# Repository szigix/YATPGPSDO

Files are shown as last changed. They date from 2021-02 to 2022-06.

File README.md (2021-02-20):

# YATPGPSDO
## Yet Another TruePosition GPSDO

This is a hardware and the corresponding firmware implemented on an STM32 BluePill board that drives a TruePosition 
GPS Disciplined Oscillator board to provide frequency reference.

For details see [my blog](https://diysquared.blogspot.com/2021/02/yatg-yet-another-trueposition-gpsdo.html).

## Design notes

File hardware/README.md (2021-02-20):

# YATPGPSDO hardware
Hardware design files for Yet Another TruePosition GPSDO
EDA software: [KiCAD](https://kicad.org/)

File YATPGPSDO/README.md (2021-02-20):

# Source for YATPGPSDO
## Yet Another TruePosition GPSDO
Arduino ide source code
Compile with 'Genetric STM32F103C Series' device under Arduino.

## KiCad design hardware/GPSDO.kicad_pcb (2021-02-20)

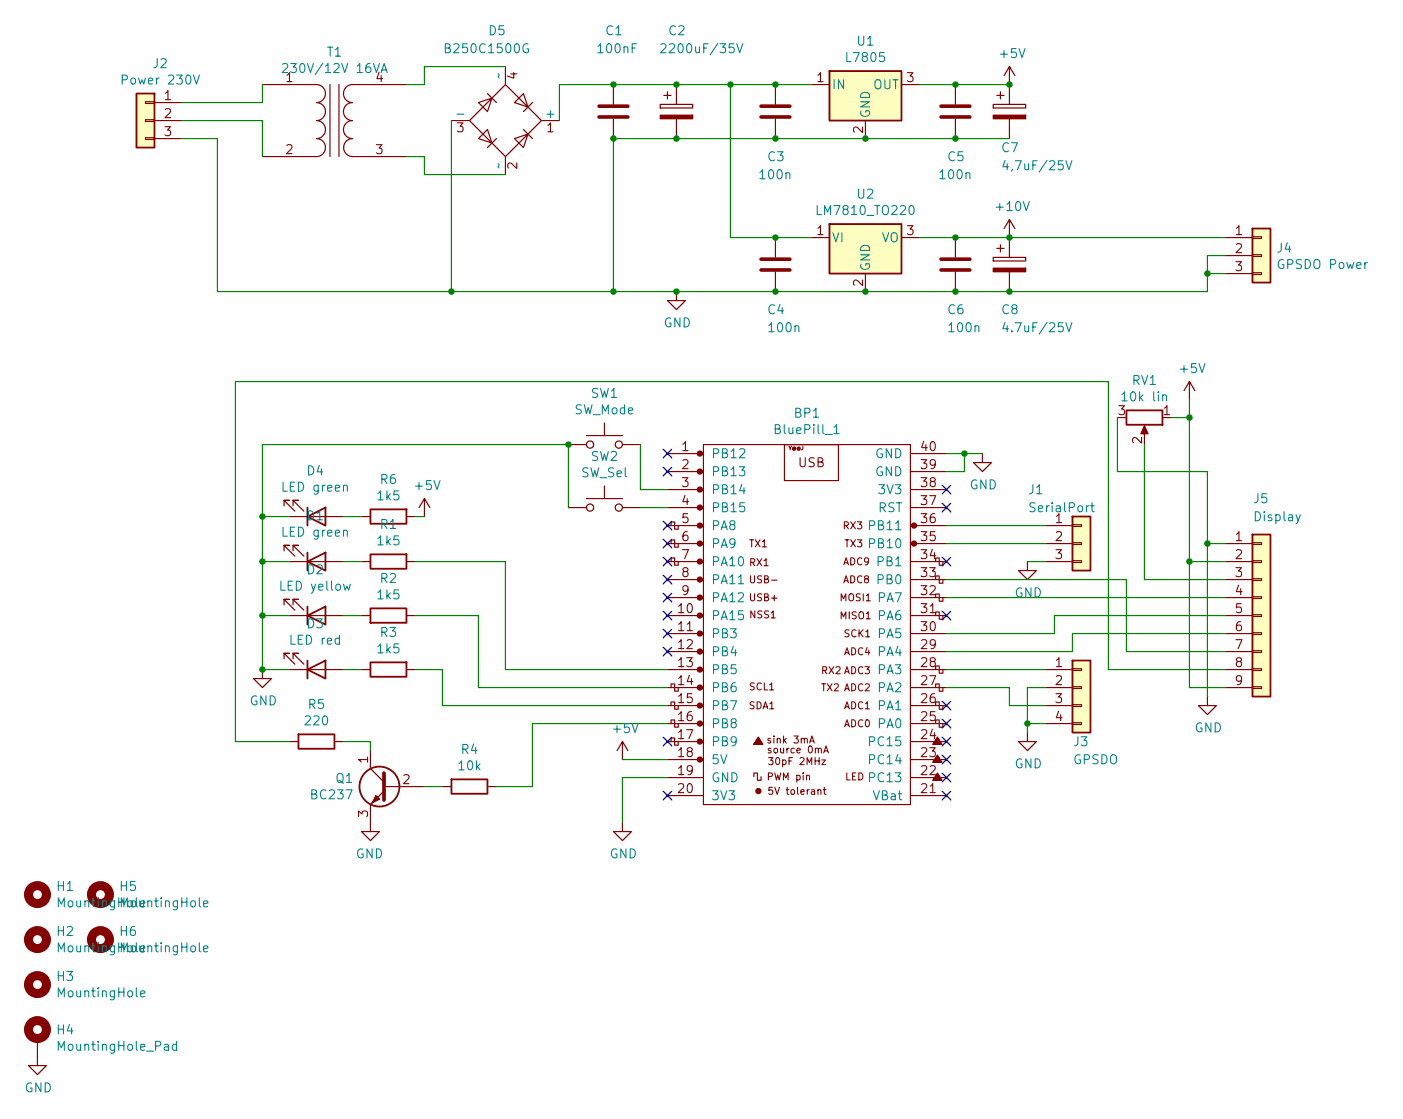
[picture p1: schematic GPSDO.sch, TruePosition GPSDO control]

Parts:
BP1: BluePill_1; STM32-BluePill
C1: 100nF; C_Disc_D5.0mm_W2.5mm_P2.50mm
C2: 2200uF/35V; CP_Radial_D16.0mm_P7.50mm
C3, C4, C5, C6: 100n; C_Disc_D5.0mm_W2.5mm_P2.50mm
C7: 4,7uF/25V; CP_Radial_D5.0mm_P2.00mm
C8: 4.7uF/25V; CP_Radial_D5.0mm_P2.00mm
D1, D4: LED green; PinHeader_1x02_P2.54mm_Vertical
D2: LED yellow; PinHeader_1x02_P2.54mm_Vertical
D3: LED red; PinHeader_1x02_P2.54mm_Vertical
D5: B250C1500G; Diode_Bridge_Round_D9.8mm
H1, H2, H3, H5, H6: MountingHole; MountingHole_3.2mm_M3_Pad
H4: MountingHole_Pad; MountingHole_3.2mm_M3_Pad_Via
J1: SerialPort; PinHeader_1x03_P2.54mm_Vertical
J2: Power 230V; SolderWire-1.5sqmm_1x03_P6mm_D1.7mm_OD3mm
J3: GPSDO; PinHeader_1x04_P2.54mm_Vertical
J4: GPSDO Power; PinHeader_1x03_P2.54mm_Vertical
J5: Display; PinHeader_1x09_P2.54mm_Vertical
Q1: BC237; TO-92_Inline
R1, R2, R3, R6: 1k5; R_Axial_DIN0207_L6.3mm_D2.5mm_P10.16mm_Horizontal
R4: 10k; R_Axial_DIN0207_L6.3mm_D2.5mm_P10.16mm_Horizontal
R5: 220; R_Axial_DIN0207_L6.3mm_D2.5mm_P10.16mm_Horizontal
RV1: 10k lin; Potentiometer_ACP_CA9-H2,5_Horizontal
SW1: SW_Mode; PinHeader_1x02_P2.54mm_Vertical
SW2: SW_Sel; PinHeader_1x02_P2.54mm_Vertical
T1: 230V/12V 16VA; Transforme_Gerth_Bv_54112
U1: L7805; TO-220-3_Vertical
U2: LM7810_TO220; TO-220-3_Vertical

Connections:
+5V: BP1.18 (5V), C5.1, C7.1, J5.2, J5.9, R6.2, RV1.1, U1.3 (OUT)
+10V: C6.1, C8.1, J4.1, U2.3 (VO)
GND: BP1.19 (GND), BP1.39 (GND), BP1.40 (GND), C1.2, C2.2, C3.2, C4.2, C5.2, C6.2, C7.2, C8.2, D1.1 (K), D2.1 (K), D3.1 (K), D4.1 (K), D5.3 (-), H4.1, J1.3, J2.3, J3.2, J3.4, J4.2, J4.3, J5.1, Q1.3 (E), RV1.3, SW1.2, SW2.2, U1.2 (GND), U2.2 (GND)
unnamed: BP1.3 (PB14), SW1.1
unnamed: BP1.4 (PB15), SW2.1
unnamed: BP1.13 (PB5), R1.2
unnamed: BP1.14 (PB6), R2.1
unnamed: BP1.15 (PB7), R3.2
unnamed: BP1.16 (PB8), R4.1
unnamed: BP1.27 (PA2), J3.3
unnamed: BP1.28 (PA3), J3.1
unnamed: BP1.29 (PA4), J5.6
unnamed: BP1.30 (PA5), J5.5
unnamed: BP1.32 (PA7), J5.4
unnamed: BP1.33 (PB0), J5.7
unnamed: BP1.35 (PB10), J1.2
unnamed: BP1.36 (PB11), J1.1
unnamed: C1.1, C2.1, C3.1, C4.1, D5.1 (+), U1.1 (IN), U2.1 (VI)
unnamed: D1.2 (A), R1.1
unnamed: D2.2 (A), R2.2
unnamed: D3.2 (A), R3.1
unnamed: D4.2 (A), R6.1
unnamed: D5.2 (~~), T1.3 (SA)
unnamed: D5.4 (~~), T1.4 (SB)
unnamed: J2.1, T1.1 (AA)
unnamed: J2.2, T1.2 (AB)
unnamed: J5.3, RV1.2
unnamed: J5.8, R5.2
unnamed: Q1.1 (C), R5.1
unnamed: Q1.2 (B), R4.2

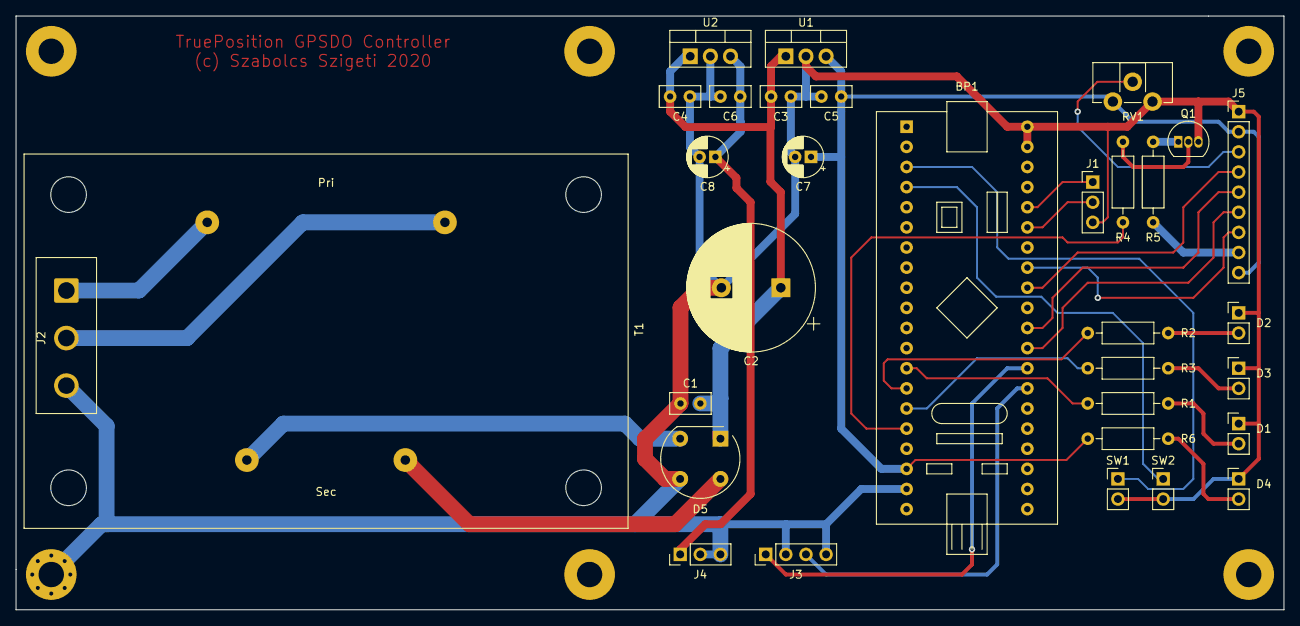
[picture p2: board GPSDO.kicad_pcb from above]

Board: 2 copper layers, 160.0 x 74.9 mm, 38 parts (0 on the bottom side), 30 nets.

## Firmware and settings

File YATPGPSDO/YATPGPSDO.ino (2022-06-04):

/*
   (c) Copyright Szabolcs Szigeti 2020-2021

   Redistribution under GPL V3. See the LICENSE file for details.


  Board: Generic STM32F103C series
  Display: 128x64 ST7920 based bitmap display in serial mode, connected to hw spi

  Additional libraries: Time and U8G2

*/
/*
   Main program for the TruePosition GPSDO
*/
#include <Time.h>
#include <TimeLib.h>
#include <EEPROM.h>
#include <U8g2lib.h>
#include <SPI.h>
#include <Wire.h>

#include "TP_GPSDO.h"

struct CLOCK gpsdoClock;        // Clock related data
struct STATUS gpsdoStatus;      // Everything about the status of the GPSDO
struct SATS gpsdoSats[NUMSAT];  // Data on the tracked satellites
struct ALERTS gpsdoAlerts;      // Alerts
struct CONFIG gpsdoConfig;      // Configuration settings

char GPSmsg[MSGMAX];            // Buffer for TruePosition messages

bool refresh = false;           // Do we need to redraw the display?

unsigned long lastMsgTime, periodicMsgTime, blinkTime, backlTime; // Timers for messages, blinking and backlight
unsigned long popupTimer;                                         // Timer for the popup message box;
unsigned long lastBtnModeTime, lastBtnSelTime, btnPress;          // Timers for the buttons
int lastBtnMode = 1, lastBtnSel = 1;                              // Button state for the Mode and Select buttons
enum DisplayModes displayMode = STATUS;                           // Current display mode
enum MenuModes menuMode = SETSURVEY;                              // Current menu mode
bool heartBeat = false;                                           // Heartbeat led
bool initPPSDBG = false;                                          // PPSDBG command sent at init
bool inAlert = false;                                             // Is there any alert?
bool blink;                                                       // The global blink used for any kind of blinking
bool popupShown = false;                                          // Is there any popup displayed?

void setup() {

  Serial2.begin(GPSDO_BAUD);      // GPSDO is on Serial 2. It is always 9600 baud.

  /*
     Set up button inputs with pull-up
  */
  pinMode(BTN_MODE, INPUT_PULLUP);
  pinMode(BTN_SEL, INPUT_PULLUP);
  /*
     Setup LEDs for output
  */
  pinMode(LED_ONBOARD, OUTPUT);
  pinMode(LED_HOLDOVER, OUTPUT);
  pinMode(LED_LOCK, OUTPUT);
  pinMode(LED_ALARM, OUTPUT);
  pinMode(LED_BACKLIGHT, OUTPUT);

  digitalWrite(LED_HOLDOVER, HIGH);
  digitalWrite(LED_LOCK, HIGH);
  digitalWrite(LED_ALARM, HIGH);
  digitalWrite(LED_BACKLIGHT, HIGH);

  EEPROM.init();
  gpsdoStatus.status = 24;
  gpsdoAlerts.tenmhz = gpsdoAlerts.onepps = true;
  gpsdoStatus.surveyed = false;
  periodicMsgTime = lastMsgTime = blinkTime = backlTime = millis();
  SetupDisplay();
  readConfig();

}

void loop() {

  for (;;) {

    if (GetGPSMsg()) {
      ProcessGPSMsg();
      lastMsgTime = millis();
      gpsdoAlerts.nogps = false;
    }

    /*
       This will detect if there is no message from the GPS for longer than NOMSGTIME
       If triggered, it will cause a GPS lost alert.
    */
    if (millis() - lastMsgTime > NOMSGTIME && gpsdoAlerts.nogps == false) {
      gpsdoAlerts.nogps = true;
      gpsdoAlerts.tenmhz = true;
      gpsdoAlerts.onepps = true;
      gpsdoStatus.status = 24;
      gpsdoStatus.initialized = false;
      gpsdoStatus.surveyed = false;
      initPPSDBG = false;
    }

    /*
       We force the GPS to provide position report every PERIODICMSG time
       TruePosition normally only reports position during survey.
    */
    if (millis() - periodicMsgTime > PERIODICMSG) {
      periodicMsgTime = millis();
      Serial2.println("$GETPOS");
    }

    /*
       Fancy blinking. This does two things:
        1 - sets the blink variable to use for blinking wherever needed.
        2 - blinks the onboard led for heartbeat.
    */
    if (millis() - blinkTime > BLINKTIME) {
      blinkTime = millis();
      blink = !blink;
      refresh = true;
      digitalWrite(LED_ONBOARD, blink ? HIGH : LOW);
    }

    /*
      Do the popup timer
    */
    if (popupShown) {
      if (millis() - popupTimer > POPUPDURATION) {
        popupShown = false;
      }
    }

    /*
           Check for button presesses and do the needed action
    */
    handleButtons();

    /*
            Set the LEDS to the current status
    */
    handleLEDs();

    /*
       This handles the lock timer. Every time the GPSDO locks, it will start the timer to show
       how long it is in lock. Any other status clears the timer.
    */
    if (gpsdoStatus.lockedSince == 0 && (gpsdoStatus.status == 0 )) {
      gpsdoStatus.lockedSince = gpsdoClock.ticks;
    } else {
      if (gpsdoStatus.status != 0 ) {
        gpsdoStatus.lockedSince = 0;
      }
    }
    /*
       Any failure sets the alert status.
       Not sure if the 10 MHz and the 1PPS alert is ever activated by the TP.
    */
    if (gpsdoAlerts.nogps || gpsdoAlerts.tenmhz || gpsdoAlerts.onepps || gpsdoAlerts.antenna) {
      if (!inAlert) {
        inAlert = true;
        refresh = true;
      }
    }
    else {
      if (inAlert) {
        inAlert = false;
        refresh = true;
      }

    }
    /*
             Only refresh display if there is a reason to refresh
    */
    if (refresh == true) {
      refresh = false;
      UpdateDisplay();
    }

  }
}

/*
   Based on the status the front panel LEDs are lit.
*/
void handleLEDs() {

  digitalWrite(LED_ALARM, inAlert ? HIGH : LOW);   // If there is an alert, light the red LED.

  switch (gpsdoStatus.status) {
    case 0:                                        // Locked: Green lock LED on
      digitalWrite(LED_LOCK, HIGH);
      digitalWrite(LED_HOLDOVER, LOW);
      break;
    case 1:                                        // Acquisition: Blink yellow holdover LED.
      digitalWrite(LED_LOCK, LOW);
      digitalWrite(LED_HOLDOVER, blink ? HIGH : LOW);
      break;
    case 2:                                          // During startup both Lock and Holdover LEDs blink
    case 9:
    case 10:
    case 11:
    case 12:
    case 13:
    case 19:
      digitalWrite(LED_LOCK, blink ? HIGH : LOW);
      digitalWrite(LED_HOLDOVER, blink ? HIGH : LOW);
      break;
    case 3:                                       // Holdover: yellow Holdover LED is on.
    case 4:
    case 5:
    case 8:
      digitalWrite(LED_HOLDOVER, HIGH);
      digitalWrite(LED_LOCK, LOW);
      break;

    case 6:                                       // No ackquisition, both LEDs are off
      digitalWrite(LED_LOCK, LOW);
      digitalWrite(LED_HOLDOVER, LOW);
      break;
    case 7:                                       // OCXO training, both LED blinks in opposite
      digitalWrite(LED_LOCK, blink ? HIGH : LOW);
      digitalWrite(LED_HOLDOVER, blink ? LOW : HIGH);
      break;
    case 14:
    case 15:
    case 16:
    case 17:
    case 18:                                        // Transition to lock: Lock LED on, Holdover LED blinks
      digitalWrite(LED_LOCK, HIGH);
      digitalWrite(LED_HOLDOVER, blink ? LOW : HIGH);
      break;
    case 20:
    case 21:
    case 22:                                       // Transition to acquisition: Lock LED blinks, Holdover LED on
      digitalWrite(LED_LOCK, blink ? LOW : HIGH);
      digitalWrite(LED_HOLDOVER, HIGH);
      break;
    default:  ;
  }

  /*
     Control the backlight.
     off (0)  - always off
     auto (1) - turns on with button press, automatically off after BACKLIGHTOFF ticks.
     on (2)   - always on
  */
  if (gpsdoConfig.backlight == 0) {
    digitalWrite(LED_BACKLIGHT, LOW);
  } else {
    if (gpsdoConfig.backlight == 2) {
      digitalWrite(LED_BACKLIGHT, HIGH);
    } else {
      digitalWrite(LED_BACKLIGHT, (millis() - backlTime > BACKLIGTHOFF) ? LOW : HIGH);
    }
  }
}

/*
   Save configuration to the EEPROM (emualted EEPROM)
   Simply writes the gpsdoConfig struct.
*/
void saveConfig() {
  int i;
  byte *p;

  p = (byte*)&gpsdoConfig;
  for (i = 0; i < sizeof(struct CONFIG); i++) {
    EEPROM.update(i, *p++);
  }

}

/*
   Read back config from EEPROM and do some sanitiy checking
*/
void readConfig() {
  int i;
  byte *p;
  struct CONFIG conf;
  p = (byte*)&conf;
  for (i = 0; i < sizeof(struct CONFIG); i++) {
    *p++ = EEPROM.read(i);
  }
  if (conf.timeoffset > 12 || conf.timeoffset < -12)
    conf.timeoffset = 0;
  if (conf.backlight > 2)
    conf.backlight = 1;
  if (conf.surveytime > 24)
    conf.surveytime = 1;
  gpsdoConfig = conf;

}

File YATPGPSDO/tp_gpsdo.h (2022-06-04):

/*
   (c) Copyright Szabolcs Szigeti 2020-2021

   Redistribution under GPL V3. See the LICENSE file for details.

*/
/*
   Configuration section
*/

#define VERSION "V1.15 2022/06/04"

#define GPSDO_BAUD  9600     // GPSDO serial speed: 9600 do not change

#define BTN_MODE  PB15       // mode button
#define BTN_SEL   PB14       // select button
#define LED_ONBOARD  PC13    // BluePill onboard LED - used for heartbeat indication
#define LED_HOLDOVER PB6     // Yellow LED for holdover
#define LED_LOCK  PB5        // Green LED for lock
#define LED_ALARM PB7        // Red LED for failure
#define LED_BACKLIGHT PB8    // Port for controlling display backlight

#define EEConfAddr  0x00      // Config address in EEPROM

#define DEBOUNCE  40         // Button debounce time in miliseconds. Shorter presses are not registred.
#define SHORTPRESS 500       // Limit for long button press.

#define NOMSGTIME 10000       // timeout if no GPS message for 10 seconds
#define PERIODICMSG 60000     // Position report every 60 seconds
#define BLINKTIME 500         // How fast things on the LEDs and display blink.
#define BACKLIGTHOFF  10000   // Backlight for 10 sec in auto mode
#define POPUPDURATION 5000    // Duration of popup messages
#define POPUPLEN  13          // Max popup text length

#define TIMEOFFSET  315964800L   // Magic correction for the 10 years off time from the gps. My TP reports time about 10 years off

#define NUMSAT 8               // Max number of satellites to track
#define MSGMAX  60             // Max msg size in chars

enum DisplayModes {STATUS, TIME, SATS, POSITION, CONFIG, ENDOFMODES};     // Display screens to flip with the Mode button
enum MenuModes {SHOWSURVEY, SETSURVEY, SETBACKLIGHT, SETOFFSET, SAVECONFIG, TRAINO}; // Various sub modes for the sreens

void ProcessGPSMsg();
bool GetGPSMsg();

void SetupDisplay();
void UpdateDisplay();
void handleButtons();
void PressBtnMode(int);
void PressBtnSel(int);
void handleLEDs();
void nextDisplay();
void showPopup(const char* text);

unsigned long millis();

/*
   System comfguration
*/
struct CONFIG {
  int timeoffset;             // Timezone settings in hours
  unsigned int surveytime;    // Default survey time
  unsigned int backlight;     // Backlight mode
};

/*
   Data from the CLOCK message
*/
struct CLOCK {
  int year;
  int month;
  int day;
  int hour;
  int minute;
  int second;
  int weekday;
  int quality;                // Time quality reported by the GPS
  uint32_t ticks;             // Unixtime ticks
};

/*
   General status of the system, mostly form the STATUS, EXTATUS messages
*/
struct STATUS {
  bool tenmhz;              // 10MHz is good. Is it ever bad???
  bool onepps;              // 1PPS id good. Same as above
  bool antenna;             // Antenna is correctly connected.
  int holdover;             // Holdover time
  int status;               // TruePosition status
  bool initialized;         // Has the TruePosition booted up?
  int nsats;                // Number of sats seen
  int tsats;                // Number of sats tracked
  float dop;                // DOP value
  float temp;               // Temperature of the unit
  int phaseoffset;          // Phase offset
  long lat;                 // Latitude
  long lon;                 // Longitude
  int elev;                 // Elevation
  bool surveying;           // Survey is in progress
  bool surveyed;            // Survey was run since last reboot
  int surveytime;           // Survey length
  float dac;                // DAC value for the OCXO steering
  char TPversion[11];       // Version string from the TruePosition board
  uint32_t lockedSince;     // Start time of current locked status, 0 if not locked
};

/*
   Data on satellites
*/
struct SATS {
  int satnum;               // Satellite PRN number
  int elevation;            // Elevation in degrees
  int azimuth;              // Azimuth in degrees
  int snr;                  // SNR value
  bool iswaas;              // Is it a WAAS/EGNOS sat?
};

/*
   Current alerts
*/
struct ALERTS {
  bool tenmhz;              // 10MHz is bad
  bool onepps;              // 1PPS is bad
  bool antenna;             // Antenna not detected
  bool nogps;               // Lost connection with TruePosition board
};

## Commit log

2021-02-20 Initial upload
    [GPSDO.kicad_pcb, GPSDO.sch]
2021-02-23 Fixed DAC and Temp resolution
    [tp_display.ino, tp_gpsdo.h, tp_message.ino]
2021-02-23 Indicate if survey was run since poweron.
2021-03-08 Tweak satellite snr display and fix typos
    [tp_button.ino, tp_display.ino, tp_gpsdo.h]
2021-04-03 Fix default survey time
    Some code tidy-up with survey time.
    Some typos squashed.
    Fixing default survey time not being saved.
    [YATPGPSDO.ino, tp_button.ino, tp_display.ino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]
2021-07-14 Fix DOP display
    Fix DOP display, it is float.
    Fix typos.
    Small code cleanups.
    [YATPGPSDO.ino, tp_display.ino, tp_gpsdo.h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]
2022-03-15 Uploaded Gerbers
    Some typos fixed, Gerbers added
    [GPSDO-B_Cu.gbr, GPSDO-B_Mask.gbr, GPSDO-B_Silkscreen.gbr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]
2022-04-09 Analog clock beautify
    Fix the very ugly analog clock display. It had pixel offset erros and the clockface bitmap was bad.
    It sucks much less now.
    [tp_display.ino, tp_gpsdo.h]
2022-06-04 Fix function proto
    Minor fix, no new version
    [tp_gpsdo.h]
